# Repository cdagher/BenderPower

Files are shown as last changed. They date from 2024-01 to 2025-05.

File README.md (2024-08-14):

# Bender ARS Power Supply

This repo serves as the home for power supply designs for the Bender Autonomous Robotic Systems (ARS) project at Boise State University. It contains hardware source files including schematics and PCB layout, as well as all firmware source files.

This source is provided as is, with no warranty whatsoever. Feel free to use it in your own projects, so long as you follow the [licensing terms](LICENSE).

## Hardware

We wanted our hardware to be flexible, as requirements can change from year to year depending on the goals of our team, design of the robot, and the competition we are targeting. As a result of this, we determined that our power supply should be *modular*. I don't mean modular like a modular ATX power supply, I mean that we can put in almost any power source, and get almost any supply voltages and currents on the output. This is obviously a tall order, so we settled for an input voltage of 0~60 VDC, a switching capacity of 55 A, and having three replaceable power modules. These modules should be cold-swappable, and can be designed to output nearly any voltage and current within a set power budget. As a final piece, we gave the board three hot-swappable power inputs so that we can power it from multiple batteries or power supplies simultaneously if we want to.

Currently, our power supply is split into three parts as follows:

1. A switching board which handles up to three inputs which are digitally fused to handle things like over-current, under- and over-voltage conditions, brown-outs, over-temperature conditions. Just to name a few. There are also three slots for our replaceable power modules, and one bank of output terminals for motor drivers directly from the input voltage.

2. A series of power modules which fit into a "standard" socket. We made a standard for ourselves from off the shelf connectors such that the modules will sit flush with the switching board, in case we need to give them a heatsink.

3. A controller. Our digital fuses on the inputs and power modules communicate over PMBus, so we need a way of controlling and coordinating everything. As long as the controller fits the bolt pattern and shape specified, it will easily bolt on to the top of the switching board and connect to everything with a wire harness. The decision to break this out into a separate board also simplified design and routing on the switching baord, and allowed for it to be designed for a cheaper 2-layer manufacturing process.

Renderings of the various boards can be seen below.

**Switching Board**

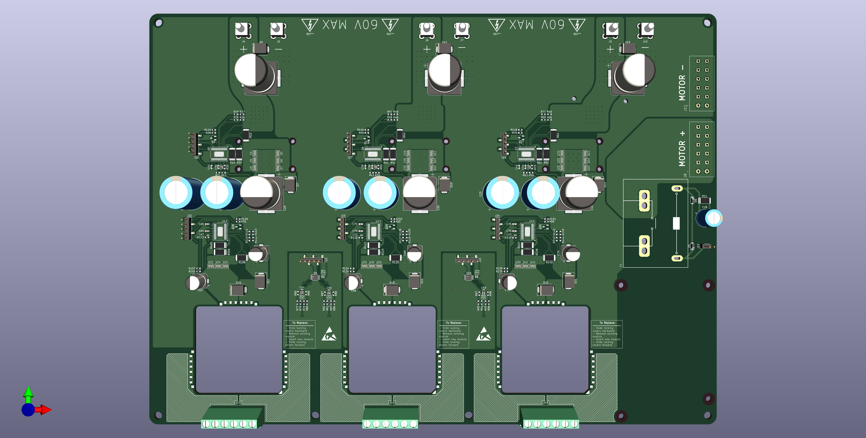
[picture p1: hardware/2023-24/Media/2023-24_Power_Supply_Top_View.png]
Top view of the switching board PCB

Top view of the switching board

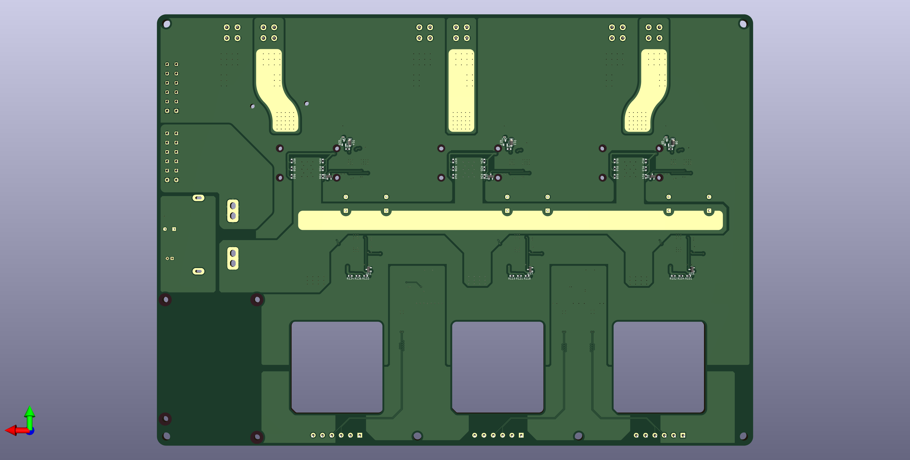
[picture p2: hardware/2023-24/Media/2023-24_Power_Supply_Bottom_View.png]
Bottom view of the switching board PCB

Bottom view of the switching board

**Power Module Examples**

TODO

**Controller**

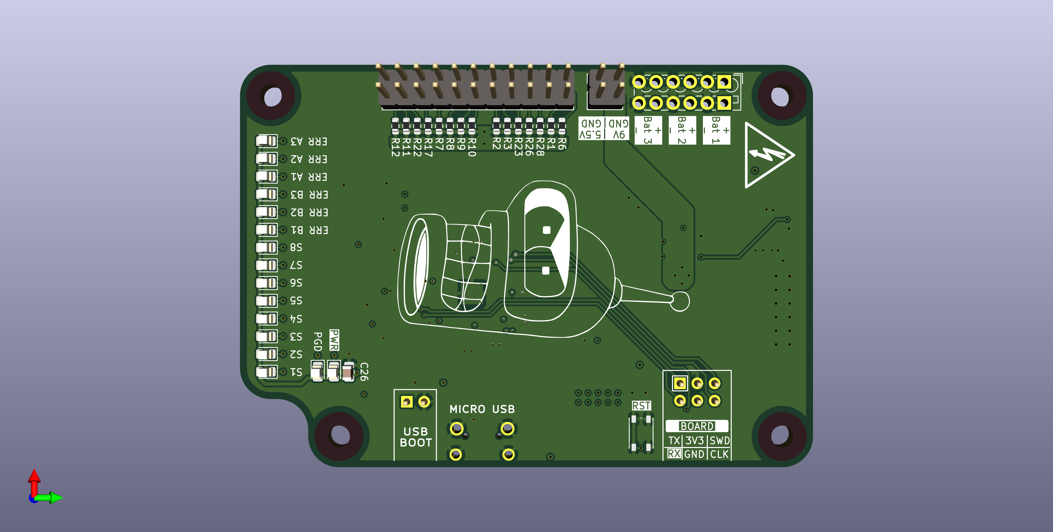
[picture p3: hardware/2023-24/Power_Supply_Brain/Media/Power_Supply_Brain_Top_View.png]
Top view of the controller PCB

Top view of the controller PCB

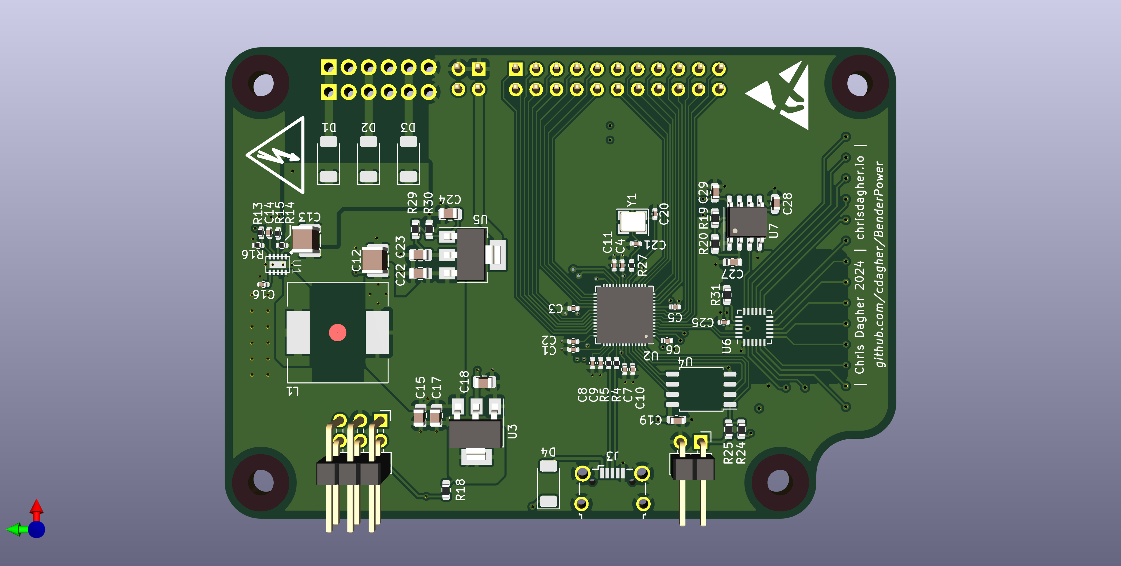
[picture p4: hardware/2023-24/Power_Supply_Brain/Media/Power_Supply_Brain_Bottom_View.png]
Bottom view of the controller PCB

Bottom View of the controller PCB

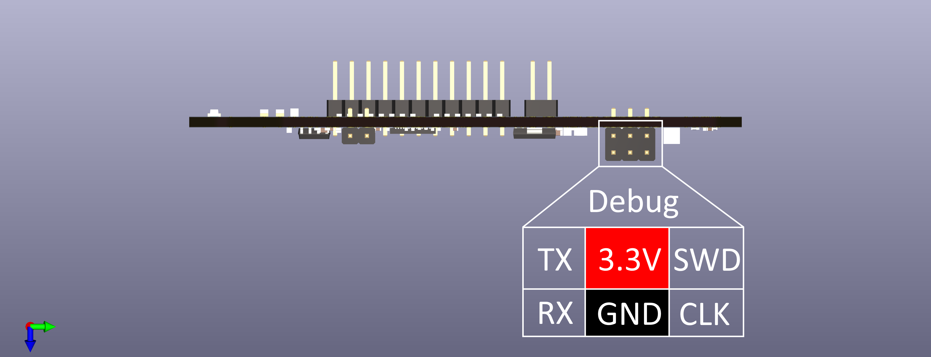
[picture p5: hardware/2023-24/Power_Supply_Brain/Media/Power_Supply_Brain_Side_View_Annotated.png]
Side view of the controller PCB

Side view of the controller PCB

## Firmware
TODO

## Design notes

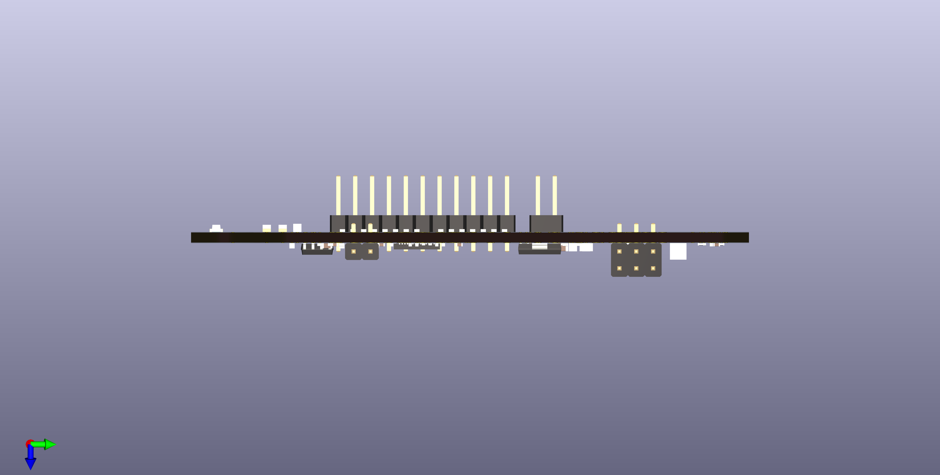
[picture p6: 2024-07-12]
hardware/2023-24/Power_Supply_Brain/Media/Power_Supply_Brain_Side_View_Ortho.png

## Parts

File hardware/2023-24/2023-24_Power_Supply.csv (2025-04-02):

Reference | Value | Footprint | Datasheet | Field4 | Indicator | MANUFACTURER | MPN | Manufacturer | STANDARD | Sim.Device | Sim.Params | Sim.Pins | Sim.Type | Qty
C22-C27 | 330u | Capacitor_THT:CP_Radial_D18.0mm_P7.50mm | https://www.we-online.com/catalog/datasheet/860241081001.pdf |  | + |  | 860241081001 |  |  |  |  |  |  | 6
C28 | 22u | Capacitor_THT:CP_Radial_D10.0mm_P5.00mm | ~ |  |  |  | EEU-ED2D220 | Panasonic |  |  |  |  |  | 1
C29, C30, C35, C36, C41, C42 | 220u | Capacitor_SMD:CP_Elec_18x17.5 | https://www.mouser.com/datasheet/2/315/ABA0000C1181-947564.pdf |  | + |  | EEV-FK2A221M |  |  |  |  |  |  | 6
C31, C37, C43 | 30n | Capacitor_SMD:C_0402_1005Metric |  |  | + |  |  |  |  |  |  |  |  | 3
C32, C33, C38, C39, C44, C45, C65, C66, C70, C71, C75, C76 | 1u | Capacitor_SMD:C_0603_1608Metric |  |  | + |  |  |  |  |  |  |  |  | 12
C34, C40, C46 | 10n | Capacitor_SMD:C_0402_1005Metric |  |  | + |  |  |  |  |  |  |  |  | 3
C50-C53, C58, C59 | 50n | Capacitor_SMD:C_0402_1005Metric | ~ |  |  |  |  |  |  |  |  |  |  | 6
C54, C55, C60 | 5p | Capacitor_SMD:C_0402_1005Metric | ~ |  |  |  |  |  |  |  |  |  |  | 3
C56, C61 | 0.1u | Capacitor_SMD:C_0402_1005Metric | ~ |  |  |  |  |  |  |  |  |  |  | 2
C57, C62 | 1.0u | Capacitor_SMD:C_0402_1005Metric | ~ |  |  |  |  |  |  |  |  |  |  | 2
C63, C64, C68, C69, C73, C74 | 22u | Capacitor_SMD:CP_Elec_8x10 | https://www.mouser.com/datasheet/2/315/ABA0000C1181-947564.pdf |  | + |  | EEE-FK2A220V |  |  |  |  |  |  | 6
C67, C72, C77 | 75n | Capacitor_SMD:C_0402_1005Metric |  |  | + |  | GRM31C5C1H753JA01L |  |  |  |  |  |  | 3
D5 | 120V | Diode_SMD:D_SOD-123 | https://www.mouser.com/datasheet/2/916/BAS21GW-1319015.pdf |  |  |  | BAS21GWX | Nexperia |  | SPICE | D,IEEE | 2=1 1=2 |  | 1
D6 | 36V | Diode_SMD:D_SOD-123 | https://www.mouser.com/datasheet/2/308/1/MMSZ5221BT1_D-2316205.pdf |  |  |  | MMSZ5258BT3G | ON Semi |  |  |  |  |  | 1
D7, D10, D13, D16, D18, D20 | 80V | Diode_SMD:D_SMC | https://www.diodes.com/assets/Datasheets/ds30020.pdf |  |  |  | B380-13-F | Diodes Inc |  |  |  |  |  | 6
D8, D11, D14 | 100V | Diode_SMD:D_SOD-123 | https://www.diodes.com/assets/Datasheets/ds30086.pdf |  |  |  | 1N4148W-7-F | Diodes Inc |  | SPICE | D,IEEE | 2=1 1=2 |  | 3
D9, D12, D15, D17, D19, D21 | 60V | Diode_SMD:D_SMC | https://www.mouser.com/datasheet/2/54/5_0smdj-1218744.pdf |  |  |  | 5.0SMDJ60A | Bourns |  |  |  |  |  | 6
J4-J7, J9, J10 | Screw_Terminal_01x01 | TerminalBlock_Wuerth:Wuerth_REDCUBE-THR_WP-THRSH_74651174_THR | https://www.we-online.com/catalog/datasheet/74651174R.pdf |  |  |  | 74651174R | Wurth |  |  |  |  |  | 6
J8, J11 | TBL007A-508-06GY | CUI:CUI_TBL007A-508-06GY |  |  |  | CUI |  |  | Manufacturer Recommendations |  |  |  |  | 2
J12 | Conn_01x02 | Connector_PinHeader_2.54mm:PinHeader_1x02_P2.54mm_Vertical | ~ |  |  |  |  |  |  |  |  |  |  | 1
J13-J15 | Screw_Terminal_01x06 | TerminalBlock_Phoenix:TerminalBlock_Phoenix_MKDS-1,5-6-5.08_1x06_P5.08mm_Horizontal | ~ |  |  |  |  |  |  |  |  |  |  | 3
J16-J18, J20-J24 | Conn_01x05_Pin | Connector_PinHeader_2.54mm:PinHeader_1x05_P2.54mm_Vertical_SMD_Pin1Left | ~ |  |  |  |  |  |  |  |  |  |  | 8
K1 | G9KB-1A DC12 | Omron:Relay_SPST_Omron_G9KB | https://www.mouser.com/datasheet/2/307/Omron_4_13_2022_G9KB_Datasheet-2939225.pdf |  |  |  | G9KB-1A DC12 | OMRON |  |  |  |  |  | 1
Q1-Q3, Q5-Q7, Q10-Q12, Q14-Q16, Q19-Q21, Q23-Q25, Q31, Q32, Q34-Q36, Q38-Q40, Q42 | ~ | Nexperia:WLCSP-8 | https://www.mouser.com/datasheet/2/916/GAN3R2_100CBE-3159465.pdf |  |  |  |  |  |  |  |  |  |  | 27
Q4, Q13, Q22, Q33, Q37, Q41 | ~ | Package_TO_SOT_SMD:SOT-23 | https://www.diodes.com/assets/Datasheets/ds30270.pdf |  |  |  | MMBT3904T-7-F | Diodes Inc |  |  |  |  |  | 6
Q8, Q17, Q26 | PNP | Package_TO_SOT_SMD:SOT-23-3 | https://www.mouser.com/datasheet/2/308/1/MMBT5401LT1_D-2316019.pdf |  |  |  | MMBT5401LT1G | ON Semi |  | PNP |  | 1=B 2=E 3=C | GUMMELPOON | 3
Q9, Q18, Q27-Q30 | NMOS | Package_TO_SOT_SMD:SOT-23-3 | https://www.mouser.com/datasheet/2/916/2N7002NXAK-1623722.pdf |  |  |  | 2N7002NXAKR | Nexperia |  | NMOS |  | 1=G 2=S 3=D | VDMOS | 6
R11 | 68 | Resistor_SMD:R_2512_6332Metric | ~ |  |  |  | 352268RFT |  |  |  |  |  |  | 1
R12-R16, R18, R34-R38, R40, R54-R58, R60 | 180 | Resistor_SMD:R_0603_1608Metric | ~ |  |  |  | RCS0603180RFKEA | Vishay |  |  |  |  |  | 18
R17, R24, R39, R46, R59, R66, R77, R80, R81, R84, R93, R96, R103, R110, R120, R127, R135, R142 | 100k | Resistor_SMD:R_0603_1608Metric | ~ |  |  |  |  |  |  |  |  |  |  | 18
R19, R41, R61, R105, R122, R137 | 56 | Resistor_SMD:R_2512_6332Metric | ~ |  |  |  | 352256RFT | TE Connectivity |  |  |  |  |  | 6
R20, R42, R62, R106, R123, R138 | 30 | Resistor_SMD:R_2512_6332Metric | ~ |  |  |  | 352230RFT | TE Connectivity |  |  |  |  |  | 6
R21, R43, R63, R107, R124, R139 | 21.3k | Resistor_SMD:R_0603_1608Metric | https://www.koaspeer.com/pdfs/RN73H.pdf |  |  |  | RN73H1JTTD2132B25 |  |  |  |  |  |  | 6
R22, R44, R64 | 500u | Resistor_SMD:R_2512_6332Metric | https://www.vishay.com/doc?30122 |  |  |  | WSLP2512L5000FEA |  |  |  |  |  |  | 3
R23, R28, R45, R50, R65, R70, R76, R92, R99 | 1k | Resistor_SMD:R_0603_1608Metric | ~ |  |  |  |  |  |  |  |  |  |  | 9
R26, R48, R68, R111, R128, R143 | 33k | Resistor_SMD:R_0603_1608Metric | ~ |  |  |  |  |  |  |  |  |  |  | 6
R27, R49, R69, R112, R129, R144 | 95k | Resistor_SMD:R_0603_1608Metric | ~ |  |  |  |  |  |  |  |  |  |  | 6
R29, R51, R71, R113, R130, R145 | 3.9k | Resistor_SMD:R_0603_1608Metric | ~ |  |  |  |  |  |  |  |  |  |  | 6
R33, R53, R73 | 45.3k | Resistor_SMD:R_0603_1608Metric |  |  |  |  |  |  |  |  |  |  |  | 3
R78, R79, R82, R83, R85-R88, R94, R95, R97, R98, R115, R116, R148-R151 | 10k | Resistor_SMD:R_0603_1608Metric | ~ |  |  |  |  |  |  |  |  |  |  | 18
R101, R102, R104, R118, R119, R121, R133, R134, R136 | 82.5 | Resistor_SMD:R_0603_1608Metric | ~ |  |  |  | ERJ-PA3F82R5V | Panasonic |  |  |  |  |  | 9
R108, R125, R140 | 1.5m | Resistor_SMD:R_2512_6332Metric | https://www.vishay.com/doc?30100 |  |  |  | WSL25121L500FEA | Vishay |  |  |  |  |  | 3
R117, R132, R147 | 28.2k | Resistor_SMD:R_0603_1608Metric | ~ |  |  |  |  |  |  |  |  |  |  | 3
U5-U7, U12, U14, U16 | LM5066 | TI:HTSSOP-28 | https://www.ti.com/general/docs/suppproductinfo.tsp?distId=26&gotoUrl=https://www.ti.com/lit/gpn/lm5066i |  |  |  |  |  |  |  |  |  |  | 6
U9, U10 | ADS1015IDGS | Package_SO:TSSOP-10_3x3mm_P0.5mm | http://www.ti.com/lit/ds/symlink/ads1015.pdf |  |  |  |  |  |  |  |  |  |  | 2
U11, U13, U15 | ~ | Regulator_Slot:50x50_slot |  |  |  |  |  |  |  |  |  |  |  | 3

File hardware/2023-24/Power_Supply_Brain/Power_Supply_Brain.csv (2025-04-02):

Reference | Value | Footprint | Datasheet | Field4 | Indicator | MPN | Manifacturer | Manufacturer | Qty
C1-C7, C10, C11 | 100n | Capacitor_SMD:C_0402_1005Metric | ~ |  |  |  |  |  | 9
C8, C9, C25 | 1u | Capacitor_SMD:C_0402_1005Metric | ~ |  |  |  |  |  | 3
C12 | 10u | Capacitor_SMD:C_1210_3225Metric |  |  | + |  |  |  | 1
C13 | 2.2u | Capacitor_SMD:C_1210_3225Metric |  |  | + |  |  |  | 1
C14 | 1u | Capacitor_SMD:C_0402_1005Metric |  |  | + |  |  |  | 1
C15 | 10u | Capacitor_SMD:C_0805_2012Metric | ~ |  |  |  |  |  | 1
C16 | 6800p | Capacitor_SMD:C_0402_1005Metric |  |  | + |  |  | Kemet | 1
C17, C22, C23 | 10u | Capacitor_SMD:C_0805_2012Metric | https://www.mouser.com/datasheet/2/447/KEM_C1006_X5R_SMD-3316465.pdf |  |  | C0805C106K3PAC7210 |  | Kemet | 3
C18 | 100n | Capacitor_SMD:C_0402_1005Metric |  |  |  |  |  | Kemet | 1
C19 | 100n | Capacitor_SMD:C_0603_1608Metric | ~ |  |  |  |  |  | 1
C20, C21 | 15p | Capacitor_SMD:C_0402_1005Metric | ~ |  |  |  |  |  | 2
C26 | 47u | Capacitor_SMD:C_0805_2012Metric | ~ |  |  |  |  |  | 1
C27 | 600p | Capacitor_SMD:C_0603_1608Metric | ~ |  |  |  |  |  | 1
C28 | DNP | Capacitor_SMD:C_0603_1608Metric | ~ |  |  |  |  |  | 1
C29 | 1u | Capacitor_SMD:C_0603_1608Metric | ~ |  |  |  |  |  | 1
C30 | 12p | Capacitor_SMD:C_0402_1005Metric | ~ |  |  |  |  |  | 1
C31 | 2200p | Capacitor_SMD:C_0402_1005Metric | ~ |  |  |  |  |  | 1
C32 | 22p | Capacitor_SMD:C_0402_1005Metric |  |  |  |  |  | Kemet | 1
C33 | 22u | Capacitor_SMD:C_0805_2012Metric |  |  |  |  |  | Kemet | 1
D1-D4 | PMEG10030ELPX | Diode_SMD:D_SOD-128 | https://www.mouser.com/datasheet/2/916/PMEG10030ELP-2938484.pdf |  |  |  |  |  | 4
D5-D20 | LED | LED_SMD:LED_0805_2012Metric | ~ |  |  |  |  |  | 16
J1 | Conn_02x03_Odd_Even | Connector_PinHeader_2.54mm:PinHeader_2x03_P2.54mm_Horizontal | ~ |  |  |  |  |  | 1
J2 | Conn_02x02_Counter_Clockwise | Connector_PinHeader_2.54mm:PinHeader_2x02_P2.54mm_Vertical | ~ |  |  |  |  |  | 1
J3 | USB_B_Micro | Connector_USB:USB_Micro-B_Wuerth_629105150521_CircularHoles | ~ |  |  |  |  |  | 1
J4 | Conn_01x02 | Connector_PinHeader_2.54mm:PinHeader_1x02_P2.54mm_Horizontal | ~ |  |  |  |  |  | 1
J5 | Screw_Terminal_01x06 | TerminalBlock_Phoenix:TerminalBlock_Phoenix_PTSM-0,5-6-2.5-V-THR_1x06_P2.50mm_Vertical | ~ |  |  | 1770995 |  | Pheonix Contact | 1
J6 | Conn_02x11_Counter_Clockwise | Connector_PinHeader_2.54mm:PinHeader_2x11_P2.54mm_Vertical | ~ |  |  |  |  |  | 1
L1 | 47u | Inductor_SMD:L_12x12mm_H6mm | https://www.mouser.com/datasheet/2/597/mss1260-270744.pdf |  |  | MSS1260-473ML |  |  | 1
R1-R3, R6, R8-R12, R18 | 10k | Resistor_SMD:R_0603_1608Metric | ~ |  |  |  |  |  | 10
R4, R5 | 27.4 | Resistor_SMD:R_0402_1005Metric | ~ |  |  |  |  |  | 2
R7, R17, R22, R23, R26, R28 | 100k | Resistor_SMD:R_0603_1608Metric | ~ |  |  |  |  |  | 6
R13 | 174k | Resistor_SMD:R_0402_1005Metric |  |  |  |  |  |  | 1
R14 | 3.3M | Resistor_SMD:R_0402_1005Metric | https://www.vishay.com/doc?28773 |  |  |  |  | Vishay | 1
R15 | 453k | Resistor_SMD:R_0402_1005Metric | https://www.vishay.com/doc?28773 |  |  |  |  | Vishay | 1
R16 | 14k | Resistor_SMD:R_0402_1005Metric | ~ |  |  |  |  | Vishay | 1
R19 | 220 | Resistor_SMD:R_0603_1608Metric | ~ |  |  |  |  |  | 1
R20 | 1.1k | Resistor_SMD:R_0603_1608Metric | ~ |  |  |  |  |  | 1
R21 | 20k | Resistor_SMD:R_0402_1005Metric | ~ |  |  |  |  | Vishay | 1
R24 | DNP | Resistor_SMD:R_0603_1608Metric | ~ |  |  |  |  |  | 1
R25 | 1k | Resistor_SMD:R_0603_1608Metric | ~ |  |  |  |  |  | 1
R27 | 1k | Resistor_SMD:R_0402_1005Metric | ~ |  |  |  |  |  | 1
R31 | 11k | Resistor_SMD:R_0603_1608Metric | ~ |  |  |  |  |  | 1
R32 | 62k | Resistor_SMD:R_0402_1005Metric |  |  |  |  |  |  | 1
R33, R35 | 30k | Resistor_SMD:R_0402_1005Metric |  |  |  |  |  |  | 2
R34 | 135k | Resistor_SMD:R_0402_1005Metric |  |  |  |  |  |  | 1
SW1 | SW_MEC_5G | Button_Switch_SMD:SW_Push_1P1T_NO_Vertical_Wuerth_434133025816 | http://www.apem.com/int/index.php?controller=attachment&id_attachment=488 |  |  |  |  |  | 1
U1 | MAX17502G | Maxim:TDFN | https://www.mouser.com/datasheet/2/609/MAX17502-3127377.pdf |  |  |  |  |  | 1
U2 | RP2040 | Package_DFN_QFN:QFN-56-1EP_7x7mm_P0.4mm_EP3.2x3.2mm_ThermalVias |  |  |  |  |  |  | 1
U3 | TPSM861252RDXR | TPSM861252:RDX0007A-MFG | https://www.ti.com/lit/gpn/tpsm861252 |  |  | TPSM861252RDXR | TI |  | 1
U4 | W25Q128JVS | Package_SO:SOIC-8_5.23x5.23mm_P1.27mm | http://www.winbond.com/resource-files/w25q128jv_dtr%20revc%2003272018%20plus.pdf |  |  |  |  |  | 1
U5 | NCP1117-5.0_SOT223 | Package_TO_SOT_SMD:SOT-223-3_TabPin2 | http://www.onsemi.com/pub_link/Collateral/NCP1117-D.PDF |  |  |  |  |  | 1
U6 | LED1642GWQTR | Package_DFN_QFN:QFN-24-1EP_4x4mm_P0.5mm_EP2.15x2.15mm | https://www.st.com/resource/en/datasheet/led1642gw.pdf |  |  |  |  |  | 1
U7 | LMC555xM | Package_SO:SOIC-8_3.9x4.9mm_P1.27mm | http://www.ti.com/lit/ds/symlink/lmc555.pdf |  |  |  |  |  | 1
Y1 | ABLS-12.000MHZ-B4-T | Crystal:Crystal_SMD_Abracon_ABM8G-4Pin_3.2x2.5mm | ~ |  |  | ABM8-272-T3 |  | Abracon | 1

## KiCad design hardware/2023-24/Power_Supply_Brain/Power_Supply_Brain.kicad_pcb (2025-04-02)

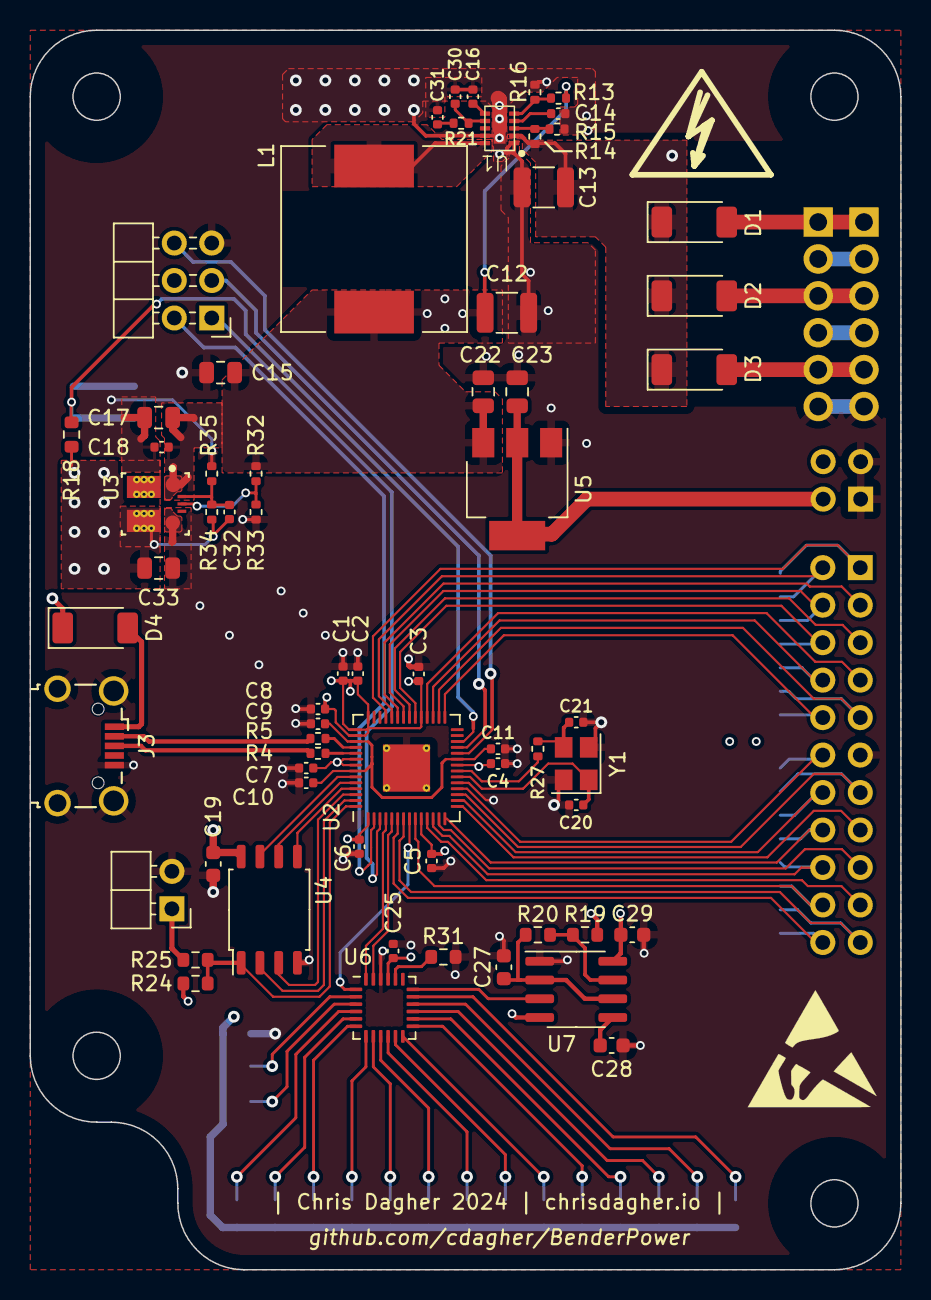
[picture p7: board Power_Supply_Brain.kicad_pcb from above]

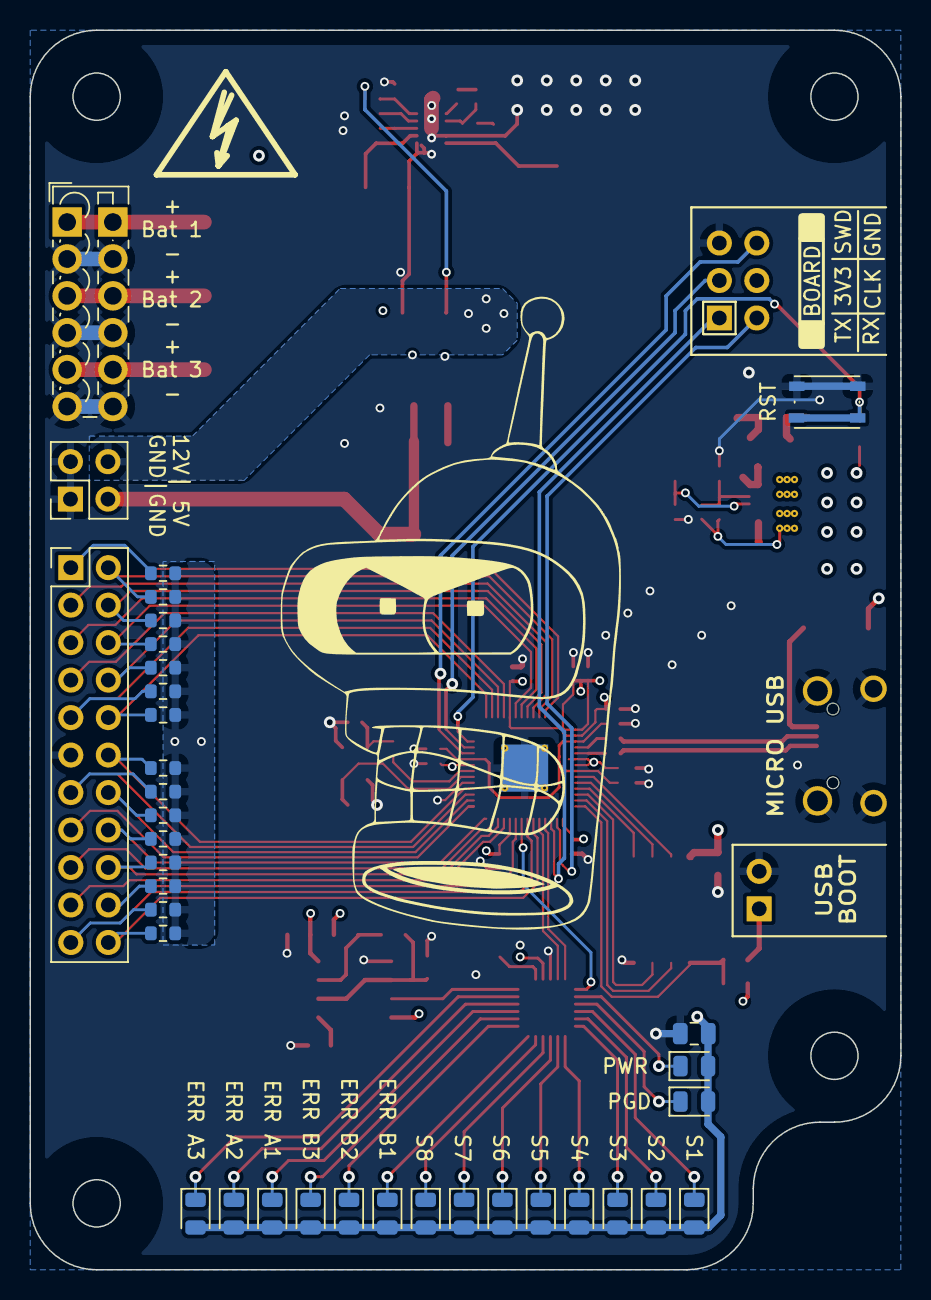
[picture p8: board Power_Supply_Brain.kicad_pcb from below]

Board: 4 copper layers, 59.0 x 84.0 mm, 101 parts (36 on the bottom side), 83 nets.

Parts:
C1, C2, C3, C4, C5, C6, C7, C10, C11, C18: 100n; C_0402_1005Metric
C8, C9, C14, C25: 1u; C_0402_1005Metric
C12: 10u; C_1210_3225Metric
C13: 2.2u; C_1210_3225Metric
C15, C17, C22, C23: 10u; C_0805_2012Metric
C16: 6800p; C_0402_1005Metric
C19: 100n; C_0603_1608Metric
C20, C21: 15p; C_0402_1005Metric
C26: 47u; C_0805_2012Metric
C27: 600p; C_0603_1608Metric
C28: DNP; C_0603_1608Metric
C29: 1u; C_0603_1608Metric
C30: 12p; C_0402_1005Metric
C31: 2200p; C_0402_1005Metric
C32: 22p; C_0402_1005Metric
C33: 22u; C_0805_2012Metric
D1, D2, D3, D4: PMEG10030ELPX; D_SOD-128
D5, D6, D7, D8, D9, D10, D11, D12, D13, D14, D15, D16, D17, D18, D19, D20: LED; LED_0805_2012Metric
J1: Conn_02x03_Odd_Even; PinHeader_2x03_P2.54mm_Horizontal
J2: Conn_02x02_Counter_Clockwise; PinHeader_2x02_P2.54mm_Vertical
J3: USB_B_Micro; USB_Micro-B_Wuerth_629105150521_CircularHoles
J4: Conn_01x02; PinHeader_1x02_P2.54mm_Horizontal
J5: Screw_Terminal_01x06; TerminalBlock_Phoenix_PTSM-0,5-6-2.5-V-THR_1x06_P2.50mm_Ver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
J6: Conn_02x11_Counter_Clockwise; PinHeader_2x11_P2.54mm_Vertical
L1: 47u; L_12x12mm_H6mm
R1, R2, R3, R6, R8, R9, R10, R11, R12, R18: 10k; R_0603_1608Metric
R4, R5: 27.4; R_0402_1005Metric
R7, R17, R22, R23, R26, R28: 100k; R_0603_1608Metric
R13: 174k; R_0402_1005Metric
R14: 3.3M; R_0402_1005Metric
R15: 453k; R_0402_1005Metric
R16: 14k; R_0402_1005Metric
R19: 220; R_0603_1608Metric
R20: 1.1k; R_0603_1608Metric
R21: 20k; R_0402_1005Metric
R24: DNP; R_0603_1608Metric
R25: 1k; R_0603_1608Metric
R27: 1k; R_0402_1005Metric
R31: 11k; R_0603_1608Metric
R32: 62k; R_0402_1005Metric
R33, R35: 30k; R_0402_1005Metric
R34: 135k; R_0402_1005Metric
SW1: SW_MEC_5G; SW_Push_1P1T_NO_Vertical_Wuerth_434133025816
U1: MAX17502G; TDFN
U2: RP2040; QFN-56-1EP_7x7mm_P0.4mm_EP3.2x3.2mm_ThermalVias
U3: TPSM861252RDXR; RDX0007A-MFG
U4: W25Q128JVS; SOIC-8_5.23x5.23mm_P1.27mm
U5: NCP1117-5.0_SOT223; SOT-223-3_TabPin2
U6: LED1642GWQTR; QFN-24-1EP_4x4mm_P0.5mm_EP2.15x2.15mm
U7: LMC555xM; SOIC-8_3.9x4.9mm_P1.27mm
Y1: ABLS-12.000MHZ-B4-T; Crystal_SMD_Abracon_ABM8G-4Pin_3.2x2.5mm

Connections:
+1V1: C9.1, C10.1, C11.1, U2.23 (DVDD), U2.45 (VREG_VOUT), U2.50 (DVDD)
+3V3: C1.1, C2.1, C3.1, C4.1, C5.1, C6.1, C7.1, C8.1, C19.1, C25.1, C26.1, C29.1, C32.1, C33.1, D5.2 (A), D6.2 (A), D7.2 (A), D8.2 (A), D9.2 (A), D10.2 (A), D11.2 (A), D12.2 (A), D13.2 (A), D14.2 (A), D15.2 (A), D16.2 (A), D17.2 (A), D18.2 (A), D19.2 (A), D20.2 (A), J1.4, R1.1, R2.2, R3.2, R6.2, R7.2, R8.1, R9.1, R10.1, R11.1, R12.1, R17.2, R18.1, R19.1, R22.2, R23.2, R24.1, R26.2, R28.2, R34.1, U2.1 (IOVDD), U2.10 (IOVDD), U2.22 (IOVDD), U2.33 (IOVDD), U2.42 (IOVDD), U2.43 (ADC_AVDD), U2.44 (VREG_IN), U2.48 (USB_VDD), U2.49 (IOVDD), U3.3 (VOUT), U3.11, U3.12, U3.13, U3.17, U3.18, U3.19, U4.8 (VCC), U6.21 (VDD), U7.4 (R), U7.8 (VCC)
+5V: C23.1, J2.3, U5.2 (VO)
+9V: C12.2 (-), C15.1, C17.1, C18.1, C22.1, J2.4, L1.2, R13.1, R32.1, U3.1 (VIN), U5.3 (VI)
/+12V_LX: L1.1, U1.10 (LX)
/LED Matrix/PWCLK: U6.18 (PWCLK), U7.3 (Q)
/LED Matrix/THR/TR: C27.1, R20.2, U7.2 (TR), U7.6 (THR)
/MCU_REG_IN: C13.2 (-), D1.1 (K), D2.1 (K), D3.1 (K), D4.1 (K), R14.1, U1.2 (VIN)
/QSPI_SCLK: U2.52 (QSPI_SCLK), U4.6 (CLK)
/QSPI_SD0: U2.53 (QSPI_SD0), U4.5 (DI(IO0))
/QSPI_SD1: U2.55 (QSPI_SD1), U4.2 (DO(IO1))
/QSPI_SD2: U2.54 (QSPI_SD2), U4.3 (IO2)
/QSPI_SD3: U2.51 (QSPI_SD3), U4.7 (IO3)
/QSPI_SS: R24.2, R25.1, U2.56 (QSPI_SS), U4.1 (~CS)
/SWCLK: J1.6, U2.24 (SWCLK)
/SWD: J1.3, U2.25 (SWD)
/UART0_RX: J1.1, U2.3 (GPIO1)
/UART0_TX: J1.2, U2.2 (GPIO0)
/USB_D_N: J3.2 (D-), R5.1
/USB_D_P: J3.3 (D+), R4.1
/XIN: C20.1, U2.20 (XIN), Y1.1
/XOUT: R27.1, U2.21 (XOUT)
/~USB_BOOT: J4.1, R25.2
ADC1_RDY: J6.10, R2.1, U2.29 (GPIO18)
ADC2_RDY: J6.9, R3.1, U2.30 (GPIO19)
ALRT_B1: J6.14, R8.2, U2.16 (GPIO13)
ALRT_B2: J6.13, R9.2, U2.17 (GPIO14)
ALRT_B3: J6.12, R10.2, U2.18 (GPIO15)
EN_AUX_1: J6.7, U2.32 (GPIO21)
EN_AUX_2: J6.5, U2.35 (GPIO23)
EN_AUX_3: J6.3, U2.37 (GPIO25)
EN_B1: J6.15, U2.15 (GPIO12)
EN_B2: J6.17, U2.13 (GPIO10)
EN_B3: J6.19, U2.11 (GPIO8)
GND: C1.2, C2.2, C3.2, C4.2, C5.2, C6.2, C7.2, C8.2, C9.2, C10.2, C11.2, C12.1 (+), C13.1 (+), C14.1 (+), C15.2, C16.1 (+), C17.2, C18.2, C19.2, C20.2, C21.2, C22.2, C23.2, C25.2, C26.2, C27.2, C28.1, C29.2, C30.2, C31.2, C33.2, J1.5, J2.1, J2.2, J3.5 (GND), J3.6 (Shield), J4.2, J5.2, J5.4, J5.6, J6.11, R15.2, R16.2, R31.1, R33.2, R35.2, SW1.2 (A), U1.1 (PGND), U1.9 (GND), U2.19 (TESTEN), U2.57 (GND), U3.4 (PGND), U4.4 (GND), U5.1 (GND), U6.22 (GND), U7.1 (GND), Y1.2 (3), Y1.4
I2C0_SCL: J6.21, R11.2, U2.7 (GPIO5)
I2C0_SDA: J6.22, R12.2, U2.6 (GPIO4)
I2C1_SCL: J6.1, R6.1, U2.39 (GPIO27_ADC1)
I2C1_SDA: J6.2, R1.2, U2.38 (GPIO26_ADC0)
LED_CLK: U2.4 (GPIO2), U6.24 (CLK)
LED_EN: U2.8 (GPIO6), U6.1 (LE)
LED_SDI: U2.5 (GPIO3), U6.23 (SDI)
unnamed: C14.2 (-), U1.4 (VCC)
unnamed: C16.2 (-), U1.6 (SS)
unnamed: C21.1, R27.2, Y1.3
unnamed: C31.1, R21.2
unnamed: D4.2 (A), J3.1 (VBUS)
unnamed: D5.1 (K), U6.2 (OUT0)
unnamed: D6.1 (K), U6.3 (OUT1)
unnamed: D7.1 (K), U6.4 (OUT2)
unnamed: D8.1 (K), U6.5 (OUT3)
unnamed: D9.1 (K), U6.6 (OUT4)
unnamed: D10.1 (K), U6.7 (OUT5)
unnamed: D11.1 (K), U6.8 (OUT6)
unnamed: D12.1 (K), U6.9 (OUT7)
unnamed: D13.1 (K), U6.10 (OUT8)
unnamed: D14.1 (K), U6.11 (OUT9)
unnamed: D15.1 (K), U6.12 (OUT10)
unnamed: D16.1 (K), U6.13 (OUT11)
unnamed: D17.1 (K), U6.14 (OUT12)
unnamed: D18.1 (K), U6.15 (OUT13)
unnamed: D19.1 (K), U6.16 (OUT14)
unnamed: D20.1 (K), U6.17 (OUT15)
unnamed: R14.2, R15.1, U1.3 (EN/UVLO)
unnamed: R13.2, R16.1, U1.5 (FB/VO)
unnamed: C30.1, R21.1, U1.7 (NC/COMP)
unnamed: R18.2, SW1.1 (A), U2.26 (RUN)
unnamed: R5.2, U2.46 (USB_DM)
unnamed: R4.2, U2.47 (USB_DP)
unnamed: R32.2, R33.1, U3.6 (EN)
unnamed: C32.2, R34.2, R35.1, U3.7 (FB)
unnamed: R31.2, U6.20 (R-EXT)
unnamed: C28.2, U7.5 (CV)
unnamed: R19.2, R20.1, U7.7 (DIS)
PGD_AUX1: J6.8, R23.1, U2.31 (GPIO20)
PGD_AUX2: J6.6, R26.1, U2.34 (GPIO22)
PGD_AUX3: J6.4, R28.1, U2.36 (GPIO24)
PGD_B1: J6.16, R7.1, U2.14 (GPIO11)
PGD_B2: J6.18, R17.1, U2.12 (GPIO9)
PGD_B3: J6.20, R22.1, U2.9 (GPIO7)
VIN_B1: D1.2 (A), J5.1
VIN_B2: D2.2 (A), J5.3
VIN_B3: D3.2 (A), J5.5

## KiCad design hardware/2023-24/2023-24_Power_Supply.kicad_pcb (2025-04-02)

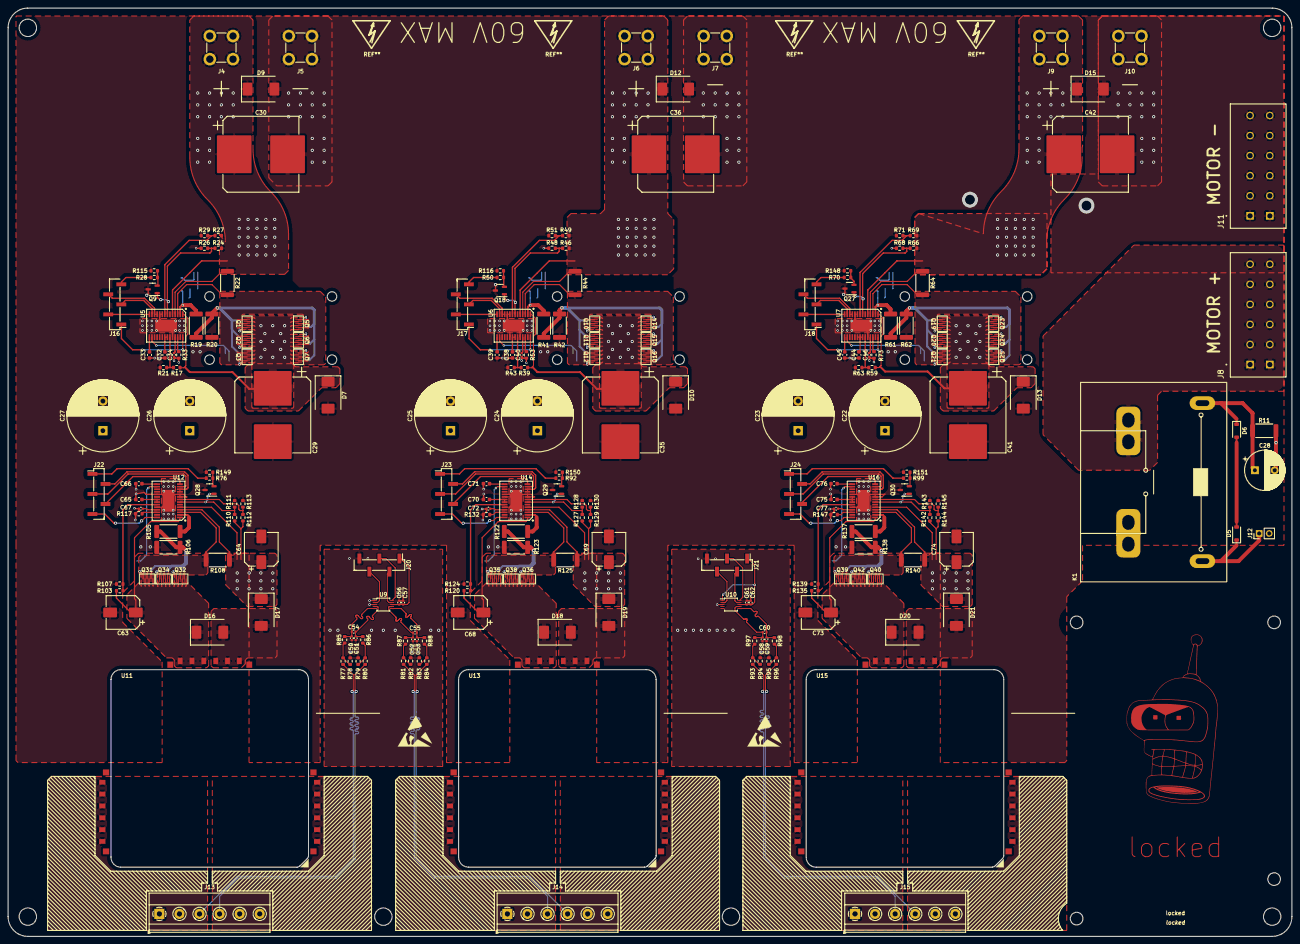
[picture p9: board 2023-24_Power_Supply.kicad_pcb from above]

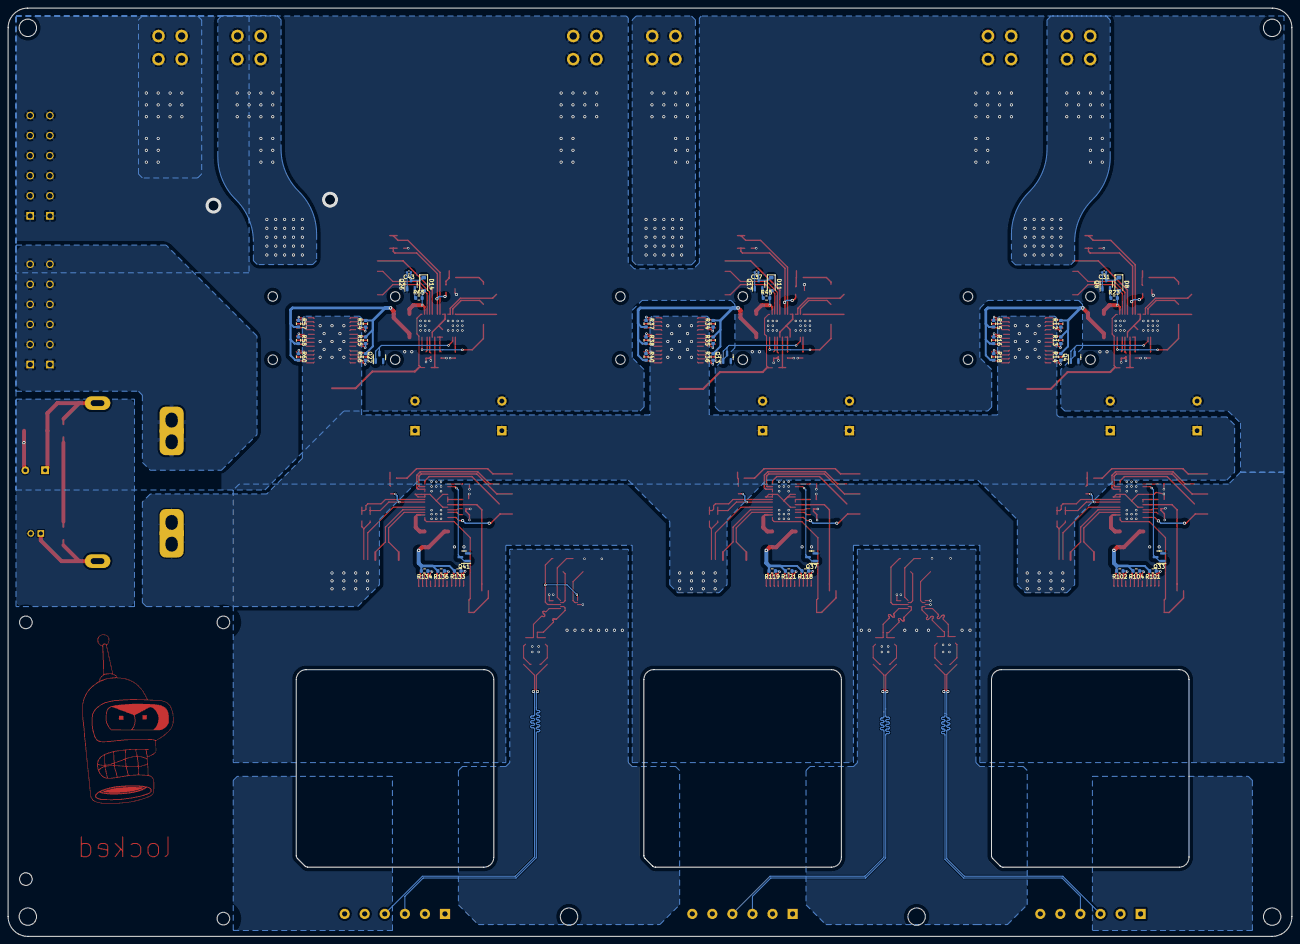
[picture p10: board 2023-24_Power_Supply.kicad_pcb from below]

Board: 2 copper layers, 325.0 x 235.0 mm, 265 parts (45 on the bottom side), 171 nets.

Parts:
C22, C23, C24, C25, C26, C27: 330u; CP_Radial_D18.0mm_P7.50mm
C28: 22u; CP_Radial_D10.0mm_P5.00mm
C29, C30, C35, C36, C41, C42: 220u; CP_Elec_18x17.5
C31, C37, C43: 30n; C_0402_1005Metric
C32, C33, C38, C39, C44, C45, C65, C66, C70, C71, C75, C76: 1u; C_0603_1608Metric
C34, C40, C46: 10n; C_0402_1005Metric
C50, C51, C52, C53, C58, C59: 50n; C_0402_1005Metric
C54, C55, C60: 5p; C_0402_1005Metric
C56, C61: 0.1u; C_0402_1005Metric
C57, C62: 1.0u; C_0402_1005Metric
C63, C64, C68, C69, C73, C74: 22u; CP_Elec_8x10
C67, C72, C77: 75n; C_0402_1005Metric
D5: 120V; D_SOD-123
D6: 36V; D_SOD-123
D7, D10, D13, D16, D18, D20: 80V; D_SMC
D8, D11, D14: 100V; D_SOD-123
D9, D12, D15, D17, D19, D21: 60V; D_SMC
J4, J5, J6, J7, J9, J10: Screw_Terminal_01x01; Wuerth_REDCUBE-THR_WP-THRSH_74651174_THR
J8, J11: TBL007A-508-06GY; CUI_TBL007A-508-06GY
J12: Conn_01x02; PinHeader_1x02_P2.54mm_Vertical
J13, J14, J15: Screw_Terminal_01x06; TerminalBlock_Phoenix_MKDS-1,5-6-5.08_1x06_P5.08mm_Horizont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
J16, J17, J18, J20, J21, J22, J23, J24: Conn_01x05_Pin; PinHeader_1x05_P2.54mm_Vertical_SMD_Pin1Left
K1: G9KB-1A-E DC12; Relay_SPST_Omron_G9KB
Q1, Q2, Q3, Q5, Q6, Q7, Q10, Q11, Q12, Q14, Q15, Q16, Q19, Q20, Q21, Q23, Q24, Q25, Q31, Q32, Q34, Q35, Q36, Q38, Q39, Q40, Q42: WLCSP-8
Q4, Q13, Q22, Q33, Q37, Q41: SOT-23
Q8, Q17, Q26: PNP; SOT-23-3
Q9, Q18, Q27, Q28, Q29, Q30: NMOS; SOT-23-3
R11: 68; R_2512_6332Metric
R12, R13, R14, R15, R16, R18, R34, R35, R36, R37, R38, R40, R54, R55, R56, R57, R58, R60: 180; R_0603_1608Metric
R17, R24, R39, R46, R59, R66, R77, R80, R81, R84, R93, R96, R103, R110, R120, R127, R135, R142: 100k; R_0603_1608Metric
R19, R41, R61, R105, R122, R137: 56; R_2512_6332Metric
R20, R42, R62, R106, R123, R138: 30; R_2512_6332Metric
R21, R43, R63, R107, R124, R139: 21.3k; R_0603_1608Metric
R22, R44, R64: 500u; R_2512_6332Metric
R23, R28, R45, R50, R65, R70, R76, R92, R99: 1k; R_0603_1608Metric
R26, R48, R68, R111, R128, R143: 33k; R_0603_1608Metric
R27, R49, R69, R112, R129, R144: 95k; R_0603_1608Metric
R29, R51, R71, R113, R130, R145: 3.9k; R_0603_1608Metric
R33, R53, R73: 45.3k; R_0603_1608Metric
R78, R79, R82, R83, R85, R86, R87, R88, R94, R95, R97, R98, R115, R116, R148, R149, R150, R151: 10k; R_0603_1608Metric
R101, R102, R104, R118, R119, R121, R133, R134, R136: 82.5; R_0603_1608Metric
R108, R125, R140: 1.5m; R_2512_6332Metric
R117, R132, R147: 28.2k; R_0603_1608Metric
U5, U6, U7, U12, U14, U16: LM5066; HTSSOP-28
U9, U10: ADS1015IDGS; TSSOP-10_3x3mm_P0.5mm
U11, U13, U15: 50x50_slot

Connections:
+5.5V: C56.1, C57.1, C61.1, C62.1, J20.1, J21.1, U9.8 (VDD), U10.1 (ADDR), U10.8 (VDD)
/Aux Outputs/Aux 1/DIODE: Q33.1 (B), Q33.3 (C), U12.16 (DIODE)
/Aux Outputs/Aux 1/GATE: R101.2, R102.2, R104.2, R105.2, R106.1
/Aux Outputs/Aux 1/GATE_OUT: R105.1, U12.2 (GATE)
/Aux Outputs/Aux 1/I2C_SCL: J22.3, U12.13 (SCLK)
/Aux Outputs/Aux 1/I2C_SDA: J22.2, U12.11 (SDAI), U12.12 (SDAO)
/Aux Outputs/Aux 1/REG_VIN: C63.1 (+), D16.1 (K), Q31.2 (S), Q32.2 (S), Q34.2 (S), R103.1, U11.1 (VIN_1), U11.2 (VIN_2), U11.3 (VIN_3), U12.1 (OUT)
/Aux Outputs/Aux 1/UVLO/EN: Q28.1 (G), R110.2, R111.2, U12.7 (UVLO/EN)
/Aux Outputs/Aux 1/VD: Q31.3 (D), Q32.3 (D), Q34.3 (D), R108.2, U12.3 (SENSE)
/Aux Outputs/Aux 1/VDD: C65.1 (+), U12.21 (VDD), U12.22 (CL)
/Aux Outputs/Aux 2/DIODE: Q37.1 (B), Q37.3 (C), U14.16 (DIODE)
/Aux Outputs/Aux 2/GATE: R118.2, R119.2, R121.2, R122.2, R123.1
/Aux Outputs/Aux 2/GATE_OUT: R122.1, U14.2 (GATE)
/Aux Outputs/Aux 2/I2C_SCL: J23.3, U14.13 (SCLK)
/Aux Outputs/Aux 2/I2C_SDA: J23.2, U14.11 (SDAI), U14.12 (SDAO)
/Aux Outputs/Aux 2/REG_VIN: C68.1 (+), D18.1 (K), Q35.2 (S), Q36.2 (S), Q38.2 (S), R120.1, U13.1 (VIN_1), U13.2 (VIN_2), U13.3 (VIN_3), U14.1 (OUT)
/Aux Outputs/Aux 2/UVLO/EN: Q29.1 (G), R127.2, R128.2, U14.7 (UVLO/EN)
/Aux Outputs/Aux 2/VD: Q35.3 (D), Q36.3 (D), Q38.3 (D), R125.2, U14.3 (SENSE)
/Aux Outputs/Aux 2/VDD: C70.1 (+), U14.21 (VDD), U14.22 (CL)
/Aux Outputs/Aux 3/DIODE: Q41.1 (B), Q41.3 (C), U16.16 (DIODE)
/Aux Outputs/Aux 3/GATE: R133.2, R134.2, R136.2, R137.2, R138.1
/Aux Outputs/Aux 3/GATE_OUT: R137.1, U16.2 (GATE)
/Aux Outputs/Aux 3/I2C_SCL: J24.3, U16.13 (SCLK)
/Aux Outputs/Aux 3/I2C_SDA: J24.2, U16.11 (SDAI), U16.12 (SDAO)
/Aux Outputs/Aux 3/REG_VIN: C73.1 (+), D20.1 (K), Q39.2 (S), Q40.2 (S), Q42.2 (S), R135.1, U15.1 (VIN_1), U15.2 (VIN_2), U15.3 (VIN_3), U16.1 (OUT)
/Aux Outputs/Aux 3/UVLO/EN: Q30.1 (G), R142.2, R143.2, U16.7 (UVLO/EN)
/Aux Outputs/Aux 3/VD: Q39.3 (D), Q40.3 (D), Q42.3 (D), R140.2, U16.3 (SENSE)
/Aux Outputs/Aux 3/VDD: C75.1 (+), U16.20 (ADR0), U16.21 (VDD), U16.22 (CL)
/Aux Outputs/VOUT_AUX1_+: J13.1, J13.2, J13.3, R77.1, U11.7 (VOUT_1), U11.8 (VOUT_2), U11.9 (VOUT_3), U11.10 (VOUT_4), U11.11 (VOUT_5), U11.12 (VOUT_6)
/Aux Outputs/VOUT_AUX1_-: J13.4, J13.5, J13.6, R80.2, U11.13 (PGND_1), U11.14 (PGND_2), U11.15 (PGND_3), U11.16 (PGND_4), U11.17 (PGND_5), U11.18 (PGND_6)
/Aux Outputs/VOUT_AUX2_+: J14.1, J14.2, J14.3, R81.1, U13.7 (VOUT_1), U13.8 (VOUT_2), U13.9 (VOUT_3), U13.10 (VOUT_4), U13.11 (VOUT_5), U13.12 (VOUT_6)
/Aux Outputs/VOUT_AUX2_-: J14.4, J14.5, J14.6, R84.2, U13.13 (PGND_1), U13.14 (PGND_2), U13.15 (PGND_3), U13.16 (PGND_4), U13.17 (PGND_5), U13.18 (PGND_6)
/Aux Outputs/VOUT_AUX3_+: J15.1, J15.2, J15.3, R93.1, U15.7 (VOUT_1), U15.8 (VOUT_2), U15.9 (VOUT_3), U15.10 (VOUT_4), U15.11 (VOUT_5), U15.12 (VOUT_6)
/Aux Outputs/VOUT_AUX3_-: J15.4, J15.5, J15.6, R96.2, U15.13 (PGND_1), U15.14 (PGND_2), U15.15 (PGND_3), U15.16 (PGND_4), U15.17 (PGND_5), U15.18 (PGND_6)
/Battery Switching/Battery 1/DIODE: Q4.1 (B), Q4.3 (C), U5.16 (DIODE)
/Battery Switching/Battery 1/GATE: R12.2, R13.2, R14.2, R15.2, R16.2, R18.2, R19.2, R20.1
/Battery Switching/Battery 1/GATE_OUT: D8.2 (A+), R19.1, R23.2, U5.2 (GATE)
/Battery Switching/Battery 1/I2C_SCL: J16.3, U5.13 (SCLK)
/Battery Switching/Battery 1/I2C_SDA: J16.4, U5.11 (SDAI), U5.12 (SDAO)
/Battery Switching/Battery 1/UVLO/EN: Q9.1 (G), R24.2, R26.2, U5.7 (UVLO/EN)
/Battery Switching/Battery 1/VD: Q1.3 (D), Q2.3 (D), Q3.3 (D), Q5.3 (D), Q6.3 (D), Q7.3 (D), R22.2, U5.3 (SENSE)
/Battery Switching/Battery 1/VDD: C32.1 (+), U5.21 (VDD), U5.22 (CL)
/Battery Switching/Battery 2/DIODE: Q13.1 (B), Q13.3 (C), U6.16 (DIODE)
/Battery Switching/Battery 2/GATE: R34.2, R35.2, R36.2, R37.2, R38.2, R40.2, R41.2, R42.1
/Battery Switching/Battery 2/GATE_OUT: D11.2 (A+), R41.1, R45.2, U6.2 (GATE)
/Battery Switching/Battery 2/I2C_SCL: J17.3, U6.13 (SCLK)
/Battery Switching/Battery 2/I2C_SDA: J17.4, U6.11 (SDAI), U6.12 (SDAO)
/Battery Switching/Battery 2/UVLO/EN: Q18.1 (G), R46.2, R48.2, U6.7 (UVLO/EN)
/Battery Switching/Battery 2/VD: Q10.3 (D), Q11.3 (D), Q12.3 (D), Q14.3 (D), Q15.3 (D), Q16.3 (D), R44.2, U6.3 (SENSE)
/Battery Switching/Battery 2/VDD: C38.1 (+), U6.21 (VDD), U6.22 (CL)
/Battery Switching/Battery 3/DIODE: Q22.1 (B), Q22.3 (C), U7.16 (DIODE)
/Battery Switching/Battery 3/GATE: R54.2, R55.2, R56.2, R57.2, R58.2, R60.2, R61.2, R62.1
/Battery Switching/Battery 3/GATE_OUT: D14.2 (A+), R61.1, R65.2, U7.2 (GATE)
/Battery Switching/Battery 3/I2C_SCL: J18.3, U7.13 (SCLK)
/Battery Switching/Battery 3/I2C_SDA: J18.4, U7.11 (SDAI), U7.12 (SDAO)
/Battery Switching/Battery 3/UVLO/EN: Q27.1 (G), R66.2, R68.2, U7.7 (UVLO/EN)
/Battery Switching/Battery 3/VD: Q19.3 (D), Q20.3 (D), Q21.3 (D), Q23.3 (D), Q24.3 (D), Q25.3 (D), R64.2, U7.3 (SENSE)
/Battery Switching/Battery 3/VDD: C44.1 (+), U7.20 (ADR0), U7.21 (VDD), U7.22 (CL)
ADC1_RDY: J20.4, U9.2 (ALERT/RDY)
ADC2_RDY: J21.4, U10.2 (ALERT/RDY)
ALRT_AUX1: J22.4, U12.14 (SMBA)
ALRT_AUX2: J23.4, U14.14 (SMBA)
ALRT_AUX3: J24.4, U16.14 (SMBA)
ALRT_B1: J16.2, U5.14 (SMBA)
ALRT_B2: J17.2, U6.14 (SMBA)
ALRT_B3: J18.2, U7.14 (SMBA)
EN_AUX_1: J22.1, R76.1
EN_AUX_2: J23.1, R92.1
EN_AUX_3: J24.1, R99.1
EN_B1: J16.5, R28.1
EN_B2: J17.5, R50.1
EN_B3: J18.5, R70.1
GND: C22.2 (-), C23.2 (-), C24.2 (-), C25.2 (-), C26.2 (-), C27.2 (-), C29.2 (-), C30.2 (-), C31.2 (-), C32.2 (-), C33.2 (-), C34.2 (-), C35.2 (-), C36.2 (-), C37.2 (-), C38.2 (-), C39.2 (-), C40.2 (-), C41.2 (-), C42.2 (-), C43.2 (-), C44.2 (-), C45.2 (-), C46.2 (-), C50.1, C51.1, C52.1, C53.1, C56.2, C57.2, C58.1, C59.1, C61.2, C62.2, C63.2 (-), C64.2 (-), C65.2 (-), C66.2 (-), C67.2 (-), C68.2 (-), C69.2 (-), C70.2 (-), C71.2 (-), C72.2 (-), C73.2 (-), C74.2 (-), C75.2 (-), C76.2 (-), C77.2 (-), D7.2 (A), D9.2 (A), D10.2 (A), D12.2 (A), D13.2 (A), D15.2 (A), D16.2 (A), D17.2 (A), D18.2 (A), D19.2 (A), D20.2 (A), D21.2 (A), J5.1, J7.1, J10.1, J11.1_A (1), J11.1_B (1__1), J11.2_A (2), J11.2_B (2__1), J11.3_A (3), J11.3_B (3__1), J11.4_A (4), J11.4_B (4__1), J11.5_A (5), J11.5_B (5__1), J11.6_A (6), J11.6_B (6__1), J20.5, J21.5, Q4.2 (E), Q8.1 (B), Q9.3 (D), Q13.2 (E), Q17.1 (B), Q18.3 (D), Q22.2 (E), Q26.1 (B), Q27.3 (D), Q28.3 (D), Q29.3 (D), Q30.3 (D), Q33.2 (E), Q37.2 (E), Q41.2 (E), R20.2, R21.2, R26.1, R29.1, R33.1, R42.2, R43.2, R48.1, R51.1, R53.1, R62.2, R63.2, R68.1, R71.1, R73.1, R78.2, R79.1, R82.2, R83.1, R94.2, R95.1, R106.2, R107.2, R111.1, R113.1, R115.2, R116.2, R117.1, R123.2, R124.2, R128.1, R130.1, R132.1, R138.2, R139.2, R143.1, R145.1, R147.1, R148.2, R149.2, R150.2, R151.2, U5.9 (AGND), U5.10 (GND), U5.24 (RETRY), U6.9 (AGND), U6.10 (GND), U6.20 (ADR0), U6.24 (RETRY), U7.9 (AGND), U7.10 (GND), U7.24 (RETRY), U9.1 (ADDR), U9.3 (GND), U10.3 (GND), U11.4 (GND_1), U11.5 (GND_2), U11.6 (GND_3), U12.9 (AGND), U12.10 (GND), U12.19 (ADR1), U12.24 (RETRY), U13.4 (GND_1), U13.5 (GND_2), U13.6 (GND_3), U14.9 (AGND), U14.10 (GND), U14.19 (ADR1), U14.20 (ADR0), U14.24 (RETRY), U15.4 (GND_1), U15.5 (GND_2), U15.6 (GND_3), U16.9 (AGND), U16.10 (GND), U16.19 (ADR1), U16.24 (RETRY)
GND2: C28.2, J12.2, R11.2
I2C1_SCL: J20.3, J21.3, U9.10 (SCL), U10.10 (SCL)
I2C1_SDA: J20.2, J21.2, U9.9 (SDA), U10.9 (SDA)
unnamed: C31.1 (+), D8.1 (K-), Q8.3 (C)
unnamed: C33.1 (+), U5.15 (VREF)
unnamed: C34.1 (+), U5.25 (TIMER)
unnamed: C37.1 (+), D11.1 (K-), Q17.3 (C)
unnamed: C39.1 (+), U6.15 (VREF)
unnamed: C40.1 (+), U6.25 (TIMER)
unnamed: C43.1 (+), D14.1 (K-), Q26.3 (C)
unnamed: C45.1 (+), U7.15 (VREF)
unnamed: C46.1 (+), U7.25 (TIMER)
unnamed: C66.1 (+), U12.15 (VREF)
unnamed: C67.1 (+), U12.25 (TIMER)
unnamed: C71.1 (+), U14.15 (VREF)
unnamed: C72.1 (+), U14.25 (TIMER)
unnamed: C76.1 (+), U16.15 (VREF)
unnamed: C77.1 (+), U16.25 (TIMER)
unnamed: D5.2 (A+), D6.2 (A)
unnamed: C28.1, D6.1 (K), K1.2 (COIL_2), R11.1
unnamed: Q1.1 (G), R12.1
unnamed: Q2.1 (G), R13.1
unnamed: Q3.1 (G), R14.1
unnamed: Q5.1 (G), R15.1
unnamed: Q6.1 (G), R16.1
unnamed: Q7.1 (G), R18.1
unnamed: Q8.2 (E), R23.1
unnamed: Q9.2 (S), R28.2, R115.1
unnamed: Q10.1 (G), R34.1
unnamed: Q11.1 (G), R35.1
unnamed: Q12.1 (G), R36.1
unnamed: Q14.1 (G), R37.1
unnamed: Q15.1 (G), R38.1
unnamed: Q16.1 (G), R40.1
unnamed: Q17.2 (E), R45.1
unnamed: Q18.2 (S), R50.2, R116.1
unnamed: Q19.1 (G), R54.1
unnamed: Q20.1 (G), R55.1
unnamed: Q21.1 (G), R56.1
unnamed: Q23.1 (G), R57.1
unnamed: Q24.1 (G), R58.1
unnamed: Q25.1 (G), R60.1
unnamed: Q26.2 (E), R65.1
unnamed: Q27.2 (S), R70.2, R148.1
unnamed: Q28.2 (S), R76.2, R149.1
unnamed: Q29.2 (S), R92.2, R150.1
unnamed: Q30.2 (S), R99.2, R151.1
unnamed: Q31.1 (G), R101.1
unnamed: Q32.1 (G), R102.1
unnamed: Q34.1 (G), R104.1
unnamed: Q35.1 (G), R118.1
unnamed: Q36.1 (G), R119.1
unnamed: Q38.1 (G), R121.1
unnamed: Q39.1 (G), R133.1
unnamed: Q40.1 (G), R134.1
unnamed: Q42.1 (G), R136.1
unnamed: R77.2, R78.1, R85.2
unnamed: R79.2, R80.1, R86.2
unnamed: R81.2, R82.1, R87.2
unnamed: R83.2, R84.1, R88.2
unnamed: R93.2, R94.1, R97.2
unnamed: R95.2, R96.1, R98.2
unnamed: R17.2, R21.1, U5.23 (FB)
unnamed: R27.1, R29.2, U5.8 (OVLO)
unnamed: R33.2, U5.26 (PWR)
unnamed: R39.2, R43.1, U6.23 (FB)
unnamed: R49.1, R51.2, U6.8 (OVLO)
unnamed: R53.2, U6.26 (PWR)
unnamed: R59.2, R63.1, U7.23 (FB)
unnamed: R69.1, R71.2, U7.8 (OVLO)
unnamed: R73.2, U7.26 (PWR)
unnamed: C51.2, C54.2, R86.1, U9.4 (AIN0)
unnamed: C50.2, C54.1, R85.1, U9.5 (AIN1)
unnamed: C53.2, C55.2, R88.1, U9.6 (AIN2)
unnamed: C52.2, C55.1, R87.1, U9.7 (AIN3)
unnamed: C59.2, C60.2, R98.1, U10.6 (AIN2)
unnamed: C58.2, C60.1, R97.1, U10.7 (AIN3)
unnamed: R103.2, R107.1, U12.23 (FB)
unnamed: R112.1, R113.2, U12.8 (OVLO)
unnamed: R117.2, U12.26 (PWR)
unnamed: R120.2, R124.1, U14.23 (FB)
unnamed: R129.1, R130.2, U14.8 (OVLO)
unnamed: R132.2, U14.26 (PWR)
unnamed: R135.2, R139.1, U16.23 (FB)
unnamed: R144.1, R145.2, U16.8 (OVLO)
unnamed: R147.2, U16.26 (PWR)
PGD_AUX1: J22.5, U12.28 (PGD)
PGD_AUX2: J23.5, U14.28 (PGD)
PGD_AUX3: J24.5, U16.28 (PGD)
PGD_B1: J16.1, U5.28 (PGD)
PGD_B2: J17.1, U6.28 (PGD)
PGD_B3: J18.1, U7.28 (PGD)
RELAY_EN: D5.1 (K-), J12.1, K1.1 (COIL_1)
VIN_B1: C30.1 (+), D9.1 (K), J4.1, R22.1, R24.1, R27.2, U5.4 (VIN_K), U5.5 (VIN)
VIN_B2: C36.1 (+), D12.1 (K), J6.1, R44.1, R46.1, R49.2, U6.4 (VIN_K), U6.5 (VIN)
VIN_B3: C42.1 (+), D15.1 (K), J9.1, R64.1, R66.1, R69.2, U7.4 (VIN_K), U7.5 (VIN)
V_MOT: J8.1_A (1), J8.1_B (1__1), J8.2_A (2), J8.2_B (2__1), J8.3_A (3), J8.3_B (3__1), J8.4_A (4), J8.4_B (4__1), J8.5_A (5), J8.5_B (5__1), J8.6_A (6), J8.6_B (6__1), K1.4 (CONTACT_2)
V_SYS: C22.1 (+), C23.1 (+), C24.1 (+), C25.1 (+), C26.1 (+), C27.1 (+), C29.1 (+), C35.1 (+), C41.1 (+), C64.1 (+), C69.1 (+), C74.1 (+), D7.1 (K), D10.1 (K), D13.1 (K), D17.1 (K), D19.1 (K), D21.1 (K), K1.3 (CONTACT_1), Q1.2 (S), Q2.2 (S), Q3.2 (S), Q5.2 (S), Q6.2 (S), Q7.2 (S), Q10.2 (S), Q11.2 (S), Q12.2 (S), Q14.2 (S), Q15.2 (S), Q16.2 (S), Q19.2 (S), Q20.2 (S), Q21.2 (S), Q23.2 (S), Q24.2 (S), Q25.2 (S), R17.1, R39.1, R59.1, R108.1, R110.1, R112.2, R125.1, R127.1, R129.2, R140.1, R142.1, R144.2, U5.1 (OUT), U6.1 (OUT), U7.1 (OUT), U12.4 (VIN_K), U12.5 (VIN), U14.4 (VIN_K), U14.5 (VIN), U16.4 (VIN_K), U16.5 (VIN)

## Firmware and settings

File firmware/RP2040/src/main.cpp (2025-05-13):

#include <stdio.h>
#include "hardware/pio.h"
#include "pico/stdlib.h"
#include "hardware/i2c.h"
#include "hardware/gpio.h"
#include "hardware/spi.h"
#include "hardware/timer.h"

#include "board.h"
#include "version.h"
#include "shell.h"
#include "shell_cmds.h"

#include "../lib/LM5066/lm5066.h"
#include "../lib/ADS1015/ads1015.h"
#include "../lib/LED1642GW/led1642gw.h"


enum LED_NUMBERS {
    PWR_ON        = 0,
    PGD           = 1,
    STATUS_1      = 2,
    STATUS_2      = 3,
    STATUS_3      = 4,
    STATUS_4      = 5,
    STATUS_5      = 6,
    STATUS_6      = 7,
    STATUS_7      = 8,
    STATUS_8      = 9,
    ERR_BATTERY_1 = 10,
    ERR_BATTERY_2 = 11,
    ERR_BATTERY_3 = 12,
    ERR_AUX_1     = 13,
    ERR_AUX_2     = 14,
    ERR_AUX_3     = 15
};


int setup() {
   printf("Initializing stdio...\n");
   stdio_init_all();

   // Initialize uart0
   printf("Initializing UART0...\n");
   uart_init(uart0, 115200);
   gpio_set_function(UART_0_TX, GPIO_FUNC_UART); // TX
   gpio_set_function(UART_0_RX, GPIO_FUNC_UART); // RX

   // Initialize i2c0
   printf("Initializing I2C0...\n");
   i2c_init(i2c0, 100 * 1000); // 100 kHz
   gpio_set_function(I2C0_SDA, GPIO_FUNC_I2C); // SDA
   gpio_set_function(I2C0_SCL, GPIO_FUNC_I2C); // SCL
   gpio_pull_up(I2C0_SDA);
   gpio_pull_up(I2C0_SCL);

   // Initialize i2c1
   printf("Initializing I2C1...\n");
   i2c_init(i2c1, 100 * 1000); // 100 kHz
   gpio_set_function(I2C1_SDA, GPIO_FUNC_I2C); // SDA
   gpio_set_function(I2C1_SCL, GPIO_FUNC_I2C); // SCL
   gpio_pull_up(I2C1_SDA);
   gpio_pull_up(I2C1_SCL);

   // Initialize GPIO for LED driver
   printf("Initializing SPI for LED driver...\n");
   gpio_set_dir(LED_CLK, GPIO_OUT); // CLK (MCU out)
   gpio_put(LED_CLK, 0); // Set CLK to low

   gpio_set_dir(LED_SDI, GPIO_OUT); // SDI (MCU out)
   gpio_put(LED_SDI, 0); // Set SDI to low

   gpio_set_dir(LED_LEN, GPIO_OUT); // Latch Enable
   gpio_put(LED_LEN, 0);


   // Initialize GPIO for battery control
   printf("Initializing GPIO for battery control...\n");
   gpio_init(BATTERY_1_EN);
   gpio_set_dir(BATTERY_1_EN, GPIO_OUT);

   gpio_init(BATTERY_1_ALERT);
   gpio_set_dir(BATTERY_1_ALERT, GPIO_IN);
   gpio_pull_up(BATTERY_1_ALERT);

   gpio_init(BATTERY_1_PGD);
   gpio_set_dir(BATTERY_1_PGD, GPIO_IN);
   gpio_pull_up(BATTERY_1_PGD);

   gpio_init(BATTERY_2_EN);
   gpio_set_dir(BATTERY_2_EN, GPIO_OUT);

   gpio_init(BATTERY_2_ALERT);
   gpio_set_dir(BATTERY_2_ALERT, GPIO_IN);
   gpio_pull_up(BATTERY_2_ALERT);

   gpio_init(BATTERY_2_PGD);
   gpio_set_dir(BATTERY_2_PGD, GPIO_IN);
   gpio_pull_up(BATTERY_2_PGD);

   gpio_init(BATTERY_3_EN);
   gpio_set_dir(BATTERY_3_EN, GPIO_OUT);

   gpio_init(BATTERY_3_ALERT);
   gpio_set_dir(BATTERY_3_ALERT, GPIO_IN);
   gpio_pull_up(BATTERY_3_ALERT);

   gpio_init(BATTERY_3_PGD);
   gpio_set_dir(BATTERY_3_PGD, GPIO_IN);
   gpio_pull_up(BATTERY_3_PGD);

   // Initialize GPIO for ADC
   printf("Initializing GPIO for ADC...\n");
   gpio_init(ADC_1_RDY);
   gpio_set_dir(ADC_1_RDY, GPIO_IN);

   gpio_init(ADC_2_RDY);
   gpio_set_dir(ADC_2_RDY, GPIO_IN);

   // Initialize GPIO for auxiliary output modules
   printf("Initializing GPIO for auxiliary output modules...\n");
   gpio_init(AUX_DUMMY_ALERT);
   gpio_set_dir(AUX_DUMMY_ALERT, GPIO_IN);
   gpio_pull_up(AUX_DUMMY_ALERT);

   gpio_init(AUX_1_EN);
   gpio_set_dir(AUX_1_EN, GPIO_OUT);
   gpio_pull_up(AUX_1_EN);

   gpio_init(AUX_2_EN);
   gpio_set_dir(AUX_2_EN, GPIO_OUT);
   gpio_pull_up(AUX_2_EN);

   gpio_init(AUX_3_EN);
   gpio_set_dir(AUX_3_EN, GPIO_OUT);
   gpio_pull_up(AUX_3_EN);

   printf("Setup complete.\n");
   return 0;
}

void led_startup(LED1642GW &led_driver) {
   led_driver.setLedOn(PWR_ON);

   for (int i = STATUS_1; i <= STATUS_8; i++) {
      led_driver.setLedOn(i);
      sleep_ms(50);
   }

   for (int i = ERR_BATTERY_1; i <= ERR_AUX_3; i++) {
      led_driver.setLedOn(i);
      sleep_ms(50);
   }

   sleep_ms(250);

   for (int i = ERR_AUX_3; i >= ERR_BATTERY_1; i--) {
      led_driver.setLedOff(i);
      sleep_ms(50);
   }

   for (int i = STATUS_8; i >= STATUS_1; i--) {
      led_driver.setLedOff(i);
      sleep_ms(50);
   }
}

int main() {

   // Wait for USB serial connection before proceeding
   printf("Waiting for USB serial connection...\n");
   stdio_flush();
   sleep_ms(5000);
   printf("USB serial connected.\n");

   printf("Starting main()...\n");
   // Initialize the board
   printf("Calling setup()...\n");
   setup();
   printf("Initializing peripherals...\n");

   lm5066 battery1 = lm5066(i2c0, BATTERY_1_ADDR, BATTERY_1_ALERT, 500e-6f);
   lm5066 battery2 = lm5066(i2c0, BATTERY_2_ADDR, BATTERY_2_ALERT, 500e-6f);
   lm5066 battery3 = lm5066(i2c0, BATTERY_3_ADDR, BATTERY_3_ALERT, 500e-6f);

   LED1642GW led_driver = LED1642GW(LED_CLK, LED_SDI, LED_LEN);
   led_driver.begin();

   ads1015 adc1 = ads1015(i2c0, ADC_1_ADDR, ADC_1_RDY);
   ads1015 adc2 = ads1015(i2c0, ADC_2_ADDR, ADC_2_RDY);

   lm5066 aux1 = lm5066(i2c1, AUX_1_ADDR, AUX_DUMMY_ALERT, 1.5e-3f);
   lm5066 aux2 = lm5066(i2c1, AUX_2_ADDR, AUX_DUMMY_ALERT, 1.5e-3f);
   lm5066 aux3 = lm5066(i2c1, AUX_3_ADDR, AUX_DUMMY_ALERT, 1.5e-3f);

   led_startup(led_driver);

   printf("Initializing shell...\n");
   shell sh;

   /* add shell devices */
   ADD_SHELL_DEVICE_LM5066(battery1,sh);
   ADD_SHELL_DEVICE_LM5066(battery2,sh);
   ADD_SHELL_DEVICE_LM5066(battery3,sh);
   ADD_SHELL_DEVICE_LM5066(aux1,sh);
   ADD_SHELL_DEVICE_LM5066(aux2,sh);
   ADD_SHELL_DEVICE_LM5066(aux3,sh);
   ADD_SHELL_DEVICE_LED1642GW(led_driver,sh);
   ADD_SHELL_DEVICE_ADS1015(adc1,sh);
   ADD_SHELL_DEVICE_ADS1015(adc2,sh);

   /* add shell commands */
   ADD_SHELL_BASE_COMMANDS(sh);
   ADD_SHELL_LM5066_COMMANDS(sh);
   ADD_SHELL_LED1642GW_COMMANDS(sh);
   ADD_SHELL_ADS1015_COMMANDS(sh);

   printf("Entering main loop...\n");
   while (1) {

      /*
      // Read battery 1 status and diagnostics
      printf("Reading battery 1 status...\n");
      stdio_flush();
      battery1.update_diagnostics();
      battery1.read_values();

      printf("Battery 1 Status:\n");
      printf("  VIN: %.3f V\n", battery1.get_vin());
      printf("  VOUT: %.3f V\n", battery1.get_vout());
      printf("  IIN: %.3f A\n", battery1.get_iin());
      printf("  PIN: %.3f W\n", battery1.get_pin());
      printf("  Temperature: %.2f C\n", battery1.get_temperature());
      printf("  Diagnostics:\n");
      printf("    VOUT UV Warn: %s\n", battery1.vout_uv_warn() ? "YES" : "NO");
      printf("    IIN OP Warn: %s\n", battery1.iin_op_warn() ? "YES" : "NO");
      printf("    VIN UV Warn: %s\n", battery1.vin_uv_warn() ? "YES" : "NO");
      printf("    VIN OV Warn: %s\n", battery1.vin_ov_warn() ? "YES" : "NO");
      printf("    Power Good: %s\n", battery1.power_good() ? "YES" : "NO");
      printf("    OT Warn: %s\n", battery1.ot_warn() ? "YES" : "NO");
      printf("    Timer Latched: %s\n", battery1.timer_latched() ? "YES" : "NO");
      printf("    MOSFET Shorted: %s\n", battery1.mosfet_shorted() ? "YES" : "NO");
      printf("    Config Preset: %s\n", battery1.config_preset() ? "YES" : "NO");
      printf("    Device Off: %s\n", battery1.device_off() ? "YES" : "NO");
      printf("    VIN UV Fault: %s\n", battery1.vin_uv_fault() ? "YES" : "NO");
      printf("    VIN OV Fault: %s\n", battery1.vin_ov_fault() ? "YES" : "NO");
      printf("    IIN Fault: %s\n", battery1.iin_fault() ? "YES" : "NO");
      printf("    Temp Fault: %s\n", battery1.temp_fault() ? "YES" : "NO");
      printf("    CML Fault: %s\n", battery1.cml_fault() ? "YES" : "NO");
      printf("    CB Fault: %s\n", battery1.cb_fault() ? "YES" : "NO");
      printf("\n");
      
      sleep_ms(1000);
      */
      sleep_ms(50);

      sh.poll_input();
   }

}

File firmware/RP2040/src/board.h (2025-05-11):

// Board configuration for RP2040

#ifndef BOARD_H
#define BOARD_H

#include "pico/stdlib.h"
#include "hardware/gpio.h"

#define BOARD_BENDER_BRAIN

// General pin configurations
#define UART_0_TX 0
#define UART_0_PIN_MODE GPIO_FUNC_UART
#define UART_0_RX 1
#define UART_0_PIN_MODE GPIO_FUNC_UART

#define I2C0_SDA 4
#define I2C0_PIN_MODE GPIO_FUNC_I2C
#define I2C0_SCL 5
#define I2C0_PIN_MODE GPIO_FUNC_I2C

#define I2C1_SDA 26
#define I2C1_PIN_MODE GPIO_FUNC_I2C
#define I2C1_SCL 27
#define I2C1_PIN_MODE GPIO_FUNC_I2C

// LED Driver pins
/*
LED Deiver is the LED1642GW from ST Microelectronics https://www.st.com/resource/en/datasheet/led1642gw.pdf

Note that the SDO pin is not used in this configuration, so there is no feedback
from the LED driver to the RP2040.
*/
#define LED_CLK 2
#define LED_CLK_MODE GPIO_FUNC_SIO
#define LED_SDI 3
#define LED_SDI_MODE GPIO_FUNC_SIO
#define LED_LEN  6
#define LED_LEN_MODE GPIO_FUNC_SIO

/* Battery Inputs 
Batteries are controlled using LM5066I ICs from Texas Instruments.

Batteries should use I2C0 for communication with the RP2040.
*/

#define BATTERY_1_ADDR 0x40
#define BATTERY_1_EN 12
#define BATTERY_1_EN_PIN_MODE GPIO_FUNC_SIO
#define BATTERY_1_ALERT 13
#define BATTERY_1_ALERT_PIN_MODE GPIO_FUNC_SIO
#define BATTERY_1_PGD 11
#define BATTERY_1_PGD_PIN_MODE GPIO_FUNC_SIO

#define BATTERY_2_ADDR 0x41
#define BATTERY_2_EN 10
#define BATTERY_2_EN_PIN_MODE GPIO_FUNC_SIO
#define BATTERY_2_ALERT 14
#define BATTERY_2_ALERT_PIN_MODE GPIO_FUNC_SIO
#define BATTERY_2_PGD 9
#define BATTERY_2_PGD_PIN_MODE GPIO_FUNC_SIO

#define BATTERY_3_ADDR 0x42
#define BATTERY_3_EN 8
#define BATTERY_3_EN_PIN_MODE GPIO_FUNC_SIO
#define BATTERY_3_ALERT 15
#define BATTERY_3_ALERT_PIN_MODE GPIO_FUNC_SIO
#define BATTERY_3_PGD 7
#define BATTERY_3_PGD_PIN_MODE GPIO_FUNC_SIO

/* ADC Inputs
ADCs are used to read the voltage output from the baord's auxiliary outputs.
The ADCs used are 2x ADS1015 from Texas Instruments

ADCs should use I2C1 for communication with the RP2040.
*/

#define ADC_1_ADDR 0x48
#define ADC_1_RDY 18
#define ADC_1_RDY_PIN_MODE GPIO_FUNC_SIO

#define ADC_2_ADDR 0x49
#define ADC_2_RDY 19
#define ADC_2_RDY_PIN_MODE GPIO_FUNC_SIO

/* Auxiliary Outputs
Auxiliary outputs are controlled using LM5066I ICs from Texas Instruments.
Note that due to a shortage of GPIO pins and board space, the auxiliary outputs
have no alert pins. This means that in order to detect a fault, the RP2040 must
poll the auxiliary outputs.

Auxiliary outputs should use I2C1 for communication with the RP2040.
*/

#define AUX_DUMMY_ALERT 16
#define AUX_DUMMY_ALERT_PIN_MODE GPIO_FUNC_SIO

#define AUX_1_ADDR 0x43
#define AUX_1_EN 21
#define AUX_1_EN_PIN_MODE GPIO_FUNC_SIO
// #define AUX_1_ALERT 20
#define AUX_1_PGD 20
#define AUX_1_PGD_PIN_MODE GPIO_FUNC_SIO

#define AUX_2_ADDR 0x44
#define AUX_2_EN 23
#define AUX_2_EN_PIN_MODE GPIO_FUNC_SIO
// #define AUX_2_ALERT 22
#define AUX_2_PGD 22
#define AUX_2_PGD_PIN_MODE GPIO_FUNC_SIO

#define AUX_3_ADDR 0x45
#define AUX_3_EN 25
#define AUX_3_EN_PIN_MODE GPIO_FUNC_SIO
// #define AUX_3_ALERT 24
#define AUX_3_PGD 24
#define AUX_3_PGD_PIN_MODE GPIO_FUNC_SIO

#endif // BOARD_H

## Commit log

2023-11-30 MCU and Battery inputs initial design
    [2023-24_Power_Supply.kicad_pcb, 2023-24_Power_Supply.kicad_sch, battery_1.kicad_sch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]
2023-12-17 regulator slot libraries
    [2023-24_Power_Supply.kicad_sch, aux_1.kicad_sch]
2023-12-17 connector datasheets
2024-01-18 Pushing for design review
    [2023-24_Power_Supply.csv, 2023-24_Power_Supply.kicad_pcb, 2023-24_Power_Supply.kicad_sch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]
2024-07-12 Hardware ready for design review
    [2023-24_Power_Supply.kicad_pcb, 2023-24_Power_Supply.kicad_sch, LED_Matrix.kicad_sch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]
2024-08-13 design updated post review
    [Power_Supply_Brain.kicad_pcb, Power_Supply_Brain.kicad_sch]
2024-08-14 Improved crystal layout. Re-ordered debug connector. Fixed silkscreen.
    [Power_Supply_Brain.kicad_pcb, Power_Supply_Brain.kicad_sch]
2025-04-02 Pushing for pre-production review
    [2023-24_Power_Supply-B_Cu.gbl, 2023-24_Power_Supply-B_Mask.gbs, 2023-24_Power_Supply-B_Paste.gbp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]
2025-04-02 Updated BoM for supply and brain
    [2023-24_Power_Supply.csv, Power_Supply_Brain.csv]
2025-05-05 Added LED1642GW lib
2025-05-05 Adding board configuration
2025-05-05 add board header interface
2025-05-05 Updated to include SPI
2025-05-05 Updated board file
2025-05-08 Added sense resistor argument to constructor. Updated telemetry logic to use sense resistor value.
2025-05-11 Update for compatibility with board design
2025-05-11 Add device addresses
2025-05-11 Update cmakelists and fixes in main
    [main.cpp]
2025-05-11 Working LED driver library
2025-05-11 LED driver working
